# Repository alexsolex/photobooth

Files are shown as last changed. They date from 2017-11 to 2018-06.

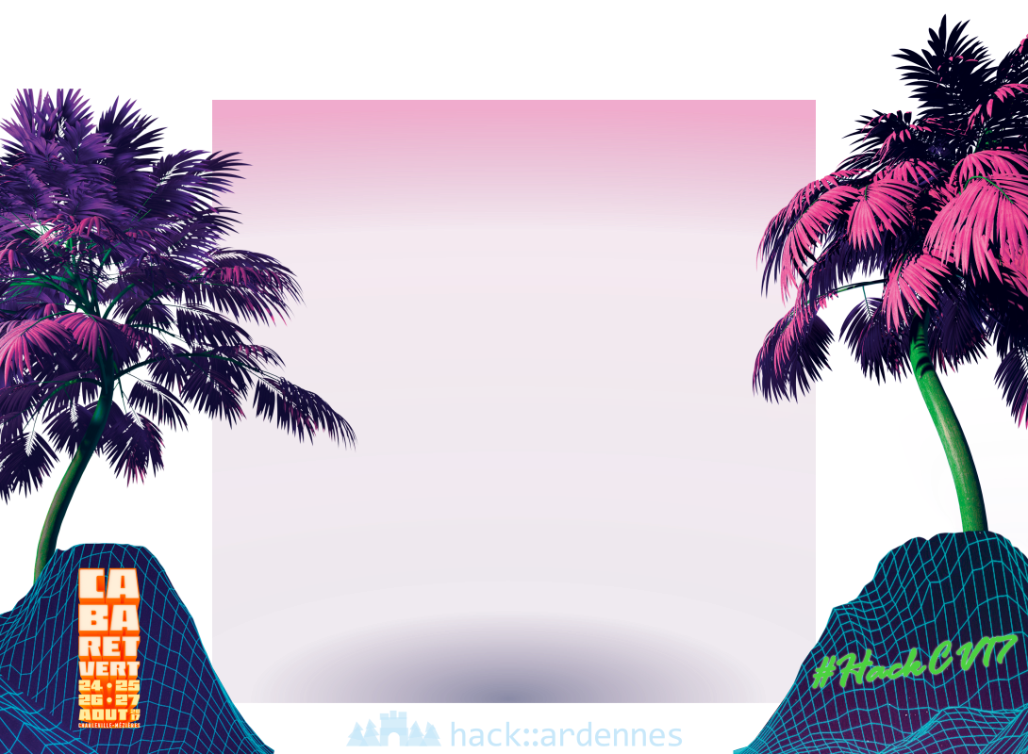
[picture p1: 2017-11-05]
stickers.png

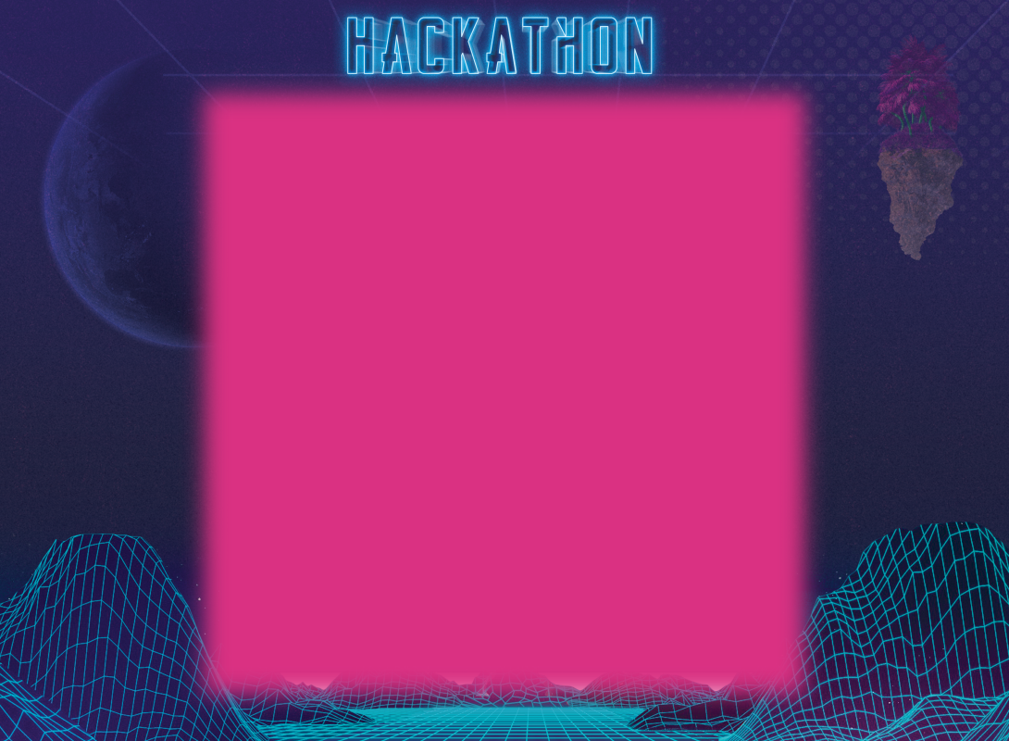
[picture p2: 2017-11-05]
background.png

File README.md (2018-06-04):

photobooth
==========

_**Photobooth made for raspberry pi**_

## matériel

Cette liste peut être adaptée selon les besoins, elle ne concerne que le matériel *électrique*/*électronique*

* 1 x Ecran avec alimentation (récupération)

* 1 x Cable écran avec adaptateur éventuel vers HDMI (dépend de la connectique de l'écran)

* 1 x Raspberry PI 3

https://www.amazon.fr/Raspberry-Pi-Carte-M%C3%A8re-Model/dp/B01CD5VC92

* 1 x Carte Micro SD classe 10

* 1 x Alimentation adaptée au Raspi (5V 3A)

https://www.amazon.fr/Aukru-Chargeur-Adaptateur-Alimentation-Raspberry/dp/B01566WOAG

* 1 x Pi Camera avec sa nappe

https://www.amazon.fr/Raspberry-Pi-1080p-Module-Cam%C3%A9ra/dp/B01ER2SKFS

* 1 x Relais 5V - 220V/10A

https://www.amazon.fr/dp/B019GTTS3K/

* 2 x lampes GU10 avec supports (par exemple mais peut être remplacé par l'éclairage de son choix, voir pourquoi pas une lampe extérieur, attention au courant consommé par les lampes qui doit être inférieur au courant que peut piloter le relais )

https://www.amazon.fr/Projecteur-Encastr%C3%A9-Douille-Ampoule-Halog%C3%A8ne/dp/B01JLNBVDQ

* 1 x connecteur c14 avec fusible et interrupteur

https://www.amazon.fr/alimentation-interrupteur-module-admission-broches/dp/B00F4MFMXE

* 1 x cable alimentation 220V PC C13

https://www.amazon.fr/Dexlan-Cordon-électrique-secteur-standard/dp/B0009M14YK

* 2 x boutons poussoirs type arcade

https://www.amazon.fr/Cewaal-Shaped-Convexity-Replacement-Illuminated/dp/B075SBK17G

* Des fils de cablage pour connecter sur le port GPIO du RPi

https://www.amazon.fr/s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

__Autre matériel__

* 1 x multiprise 220v (pour connecter l'écran et l'alimentation de raspberry)
* Du fil électrique 1.5mm² (cablage des lampes)
* Des dominos pour le raccordement électrique
* un fer à souder / de l'étain

## Installation (WIP)

__Prérequis :__
* J'ai choisi volontairement de ne pas rentrer dans les détails de l'utilisation d'un raspberry pi.  
* Raccorder son raspberry Pi au réseau et à internet pour effectuer les mises à jours et autres installations
* Brancher clavier/souris et écran ou se connecter en SSH pour effectuer les manipulations
* Avoir quelques notions d'électricité (ATTENTION quand vous manipulez du 220v !)
* Avoir quelques notions d'électronique

### Software (WIP)

1. Installer Raspbian sur la carte microSD et procéder à toutes les mises à jour  
 `sudo apt-get update `  
 `sudo apt-get dist-upgrade `  
 `sudo rpi-update `  ( Je déconseille celle-ci car elle a ruiné la résolution de mon écran, j'ai du réinstaller rasbian pour retrouver un setup fonctionnel)
 Puis reboot  
 
0. Configurations sur raspbian
La plupart de ces configurations se font soit depuis l'interface graphique soit via la console en tapant `sudo raspi-config`
* Connexion au réseau internet
* Configuration du hostname (utile lorsqu'on ne connait pas à priori l'adresse IP)
* Clavier en FR
* Locale en FR / France/ UTF8
* Timezone Europe/Paris (très important étant donné que les photos seront horodatées avec l'heure système)
* (Wifi country FR)
* Enable Camera + reboot
* Enable SSH + reboot
* Enable I2C + reboot
* Underscan = disabled (j'avais des bordures inutilisées sur l'écran)
* Changement du mot de passe de l'utilisateur `pi`  
`sudo passwd pi` puis saisie 2 fois du nouveau mot de passe  
`sudo reboot`
* extension du filesystem pour occuper la totalité de la carte mémoire  
`sudo raspi-config`  
(pensez à vérifier régulièrement que les configurations sont correctement prises en compte `sudo reboot`)
* installation du driver v4l2 (Attention il s'agit de la lettre L minuscule entre le 4 et le 2)  
`sudo nano /etc/modules`  
Ajouter la ligne suivante :  
`bcm2835-v4l2`  
* Préserver la carte SD en installant des logs dans la mémoire
`sudo nano /etc/fstab`  
ajouter  
`tmpfs /var/log tmpfs defaults,noatime,nosuid,mode=0755,size=100m 0 0`
On peut ajouter également les dossiers suivants :
`tmpfs /tmp tmpfs defaults,noatime,nosuid,size=100m 0 0`  
`tmpfs /var/tmp tmpfs defaults,noatime,nosuid,size=30m 0 0`  
``tmpfs /var/log tmpfs defaults,noatime,nosuid,mode=0755,size=100m 0 0`  
`tmpfs /var/run tmpfs defaults,noatime,nosuid,mode=0755,size=2m 0 0`  
`tmpfs /var/spool/mqueue tmpfs defaults,noatime,nosuid,mode=0700,gid=12,size=30m 0 0`  

3. Installer/mettre à jour les librairies python : (version indicatives basées sur mon setup d'origine)

  * pip pour installer les librairies (8.1.2) (déjà installé sur raspbian)
  * dropbox (4.0)  
  `sudo pip install dropbox`
  * facebook-sdk (2.0.0)  
  `sudo pip install facebook-sdk`
  * piexif (1.0.8) !! ATTENTION !! La version 1.0.10 ne fonctionne pas  
  `sudo pip install piexif==1.0.8`
  * qrcode (5.0.1)  
  `sudo pip install qrcode`
  * pygame (1.9.2a0) (déjà installé sur raspbian)
  * picamera (1.13) (déjà installé sur raspbian)
  * Pillow (2.6.1)  (déjà installé sur raspbian)  
  `sudo pip install pillow`
  * RPi.GPIO (0.6.3)  (déjà installé sur raspbian)  
  `sudo pip install rpi.gpio`
  * twython (3.3.0)  (déjà installé sur raspbian)  
  `sudo pip install twython` 
0. installer le script photobooth  
`sudo git clone https://github.com/alexsolex/photobooth.git`
0. enlever le fichier dummy.txt du répertoire shots (à corriger)  
`sudo rm dummy.txt`
0. Tester la caméra  
`raspistill -o image.jpg` doit afficher la vue de la caméra pendant quelques secondes puis fermer
0. Désactiver la led de la picamera(optionnel mais évite la chauffe)  
Editer le fichier config `sudo nano /boot/config.txt`  
Puis ajouter la ligne suivante à la fin : `disable_camera_led=1`

0. Désinstaller la suite libreoffice ainsi que d'autres applications inutiles.  
`sudo apt-get remove --purge libreoffice*`  
`sudo apt-get clean`  
`sudo apt-get autoremove`  

#### Configuration du photobooth

##### Envoyer les photos sur un compte dropbox

1. Aller sur https://www.dropbox.com/developers/

2. Créer une app :

* ChooseAPI : Dropbox API
* Choose the type of access you need : App folder
* Name your app : (doit être unique) mySuperPhotoboothDropbox
* [Create app]

3. Chercher `Generated access token`, puis cliquer sur `[Generate]` pour récupérer le token (chaine alphanumérique)

Configurer Dropbox pour votre photobooth :

Editer le fichier `setup.py`, trouver et modifier les lignes comme suit

> `DROPBOX_UPLOAD = True`  
> `dropboxToken = "coller_ici_le_token_généré_précédemment"`

0. Lancer le photobooth automatiquement au démarrage (TODO)

Editer le fichier /etc/rc.local et ajouter les commandes :  
>`cd /home/pi/photoboothfolder`  
>`sudo python photobooth.py`  

### Hardware (WIP)

#### Notes préliminaires
Je n'expliquerais pas ici la construction du boitier, chacun pouvant le réaliser selon ses compétences, ses besoins ... Cependant voici quelques remarques constaté avec l'usage :

* Pensez à la stabilité du photobooth. Il va être manipulé par plein de monde et certainement aussi des enfants !
* Pensez aux enfants : si les boutons sont trop haut, les enfants risquent de se mettre en danger (monter sur une chaise) ou encore de s'accrocher au photobooth pour pouvoir le manipuler
* Les utilisateurs regarderont l'écran pendant la prise de vue mais pas la caméra : La caméra devra être au plus proche de l'écran de manière à ce que le regard ne semble pas trop décalé sur la photo.
* Les lampes s'allumeront pendant la prise de vue (pour adapter l'autofocus) ce qui éblouira les utilisateurs. Pensez-y dans la conception et adaptez la position des lumières pour un compromis éclairage suffisant, mais pas trop éblouissant.

#### Câblage
ATTENTION : vous trouverez sur le net des schémas de numérotation du port GPIO correspondant à votre raspberry. 

Relais pour le flash (3 fils):  
\+ ---> pin #2 (5v PWR)  
\- ---> pin #14 (GND)  
s ---> pin #15 (GPIO22)

Bouton rouge (prise de vue / annulation) :  
Pin #6 (GND)  
Pin #7 (GPIO4)

Bouton bleu (enregistrement / diaporama) :  
Pin #8 (GPIO14)  
Pin #9 (GND)

Les boutons ont été câblés avec une résistance de tirage en série et un condensateur (valeur à préciser) pour éviter les parasites et les rebonds de contact (debounce)

## Boitier
Ce paragraphe est indicatif afin de vous donner des pistes sur sa réalisation.

J'ai pour ma part réalisé le mien en DAO (autocad en licence etudiant/professeur). J'ai mesuré au pied à coulisse tous les encombrements des éléments à positionner (écran, boutons, lampes, prises usb et ethernet, prise femelle 200v et interrupteur), que j'ai redessiné sur autocad afin de prévoir les encombrement dans le boitier.

Les plans ont été réalisés afin d'être utilisés par une découpe laser. 

J'ai pris soin de connaitre l'encombrement maximum supporté par la découpe laser afin de pouvoir faire les découpe en un seul morceau. J'ai également demandé au fablab l'épaisseur (kerf) du laser (0.1mm dans mon cas). Ceci est utile car j'ai fait un assemblage de type "cross fingers" et il faut prendre en compte l'épaisseur de la découpe afin que les morceaux s'assemblent en forcant pour assurer le maintien.

Pour dessiner les "cross fingers" j'ai utilisé un outil en ligne : https://makeabox.io ce qui est tout de même bien plus simple que le faire à la main :). Cet outil génère un fichier pdf qu'on peut réimporter dans autocad pour le modifier et y dessiner les autres parties à découper.

Remarque : J'ai utilisé du médium 6mm qui était la limite que pouvait découper le laser en épaisseur (j'ai donc eut de la chance mais le fablab a du réutiliser un medium certainement de meilleure qualité). A de telles épaisseurs de découpe, le faisceau laser qui est conique a tendance à bruler plus la partie supérieur que la partie inférieure, ce qui engendre des découpes en biseau assez visibles. Cependant cela n'a pas empêché le montage final.

Les plans que j'ai utilisé sont disponibles dans le dossier 'documentation' du dépôt.

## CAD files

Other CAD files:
documentation/photobooth_plan_decoupe.dwg

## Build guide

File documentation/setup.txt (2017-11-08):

A faire pour préparer le RPI (documentation à réaliser)
- installation de rasbian + màj
- activation SSH
- faire de la place sur rasbian 
	(nettoyer le superflux)
- install / MàJ Python
- dépendances python 
	- pygame
	- PIL
	- ...
- setup picam
- Cablage GPIO
- Mise à jour de l'horloge auto sur internet

(et sans doute d'autres choses qui m'échappent)

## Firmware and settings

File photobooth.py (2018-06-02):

# -*- coding: utf-8 -*-

import pygame
import pygame.camera
from pygame.locals import *
import time,random,datetime
import shutil,os.path
from PIL import Image, ImageOps, ImageEnhance, ImageDraw, ImageFont
import socket
import fcntl
import struct
import config
import facebook
import piexif
#TODO
# - ajouter une option pour permettre de ne pas activer le slideshow
# - ajouter un timeout pour lancer le slideshow sur l'accueil 
# - Faire un système de lancement automatique de la prise de vue (pour attirer l'attention avec les flash)
# - terminer la factorisation des paramètres
# - améliorer la configuration (wifi, ...)
#DONE
# - design global
# - compte à rebour sur les différentes étapes
# - grossir le logo
# - appui sur A lors du compte à rebour pour revenir à la préparation
# - prévoir l'absence de réseau
# - ajouter le logo hackardenes sur le polaroid
# - réduire le polaroid pour ne pas perdre en qualité sur la photo
# - réparer le décompte avant abandon de la photo

############################################################################################
#  CONFIGURATION                                                                           #
############################################################################################

# Pour envoyer les tweets sans les messages 'officiels' (True : le message est basique / False : le message est aléatoire parmis les messages configurés)
TEST = False 

# Mode Debug : DEBUG = True pour ne pas envoyer de tweet du tout / False pour envoyer des Tweets
DEBUG = False

# Transform the picture into a polaroid photographe
RENDER_AS_POLAROID = True

# use a white background to act like a flash when shooting picture
USE_SCREEN_AS_FLASH = False

# Run the booth in full screen
RUN_FULLSCREEN = True

# if not full screen, size of the window
WINDOWED_MODE_SIZE = (800,800)

# use GPIO for button and/or flash
USE_GPIO = True

# Camera settings 
HFLIP = False
VFLIP = True

# FIN DE LA CONFIGURATION
#######################################################

# QRcode temporaire
QRCODE_FILENAME = "_temporaryQRCode.jpg"
# Nom des fichiers temporaires
TEMPORARY_FILENAME = "_temporary.jpg"
# polaroid filename
POLA_FILENAME = "_pola"+TEMPORARY_FILENAME #+".png"
# TODO : modifier le chemin et distinguer la photo prise de la photo générée
#TEMP_SHOOT_FILENAME = "shoot.jpg" #photo prise brut
#TEMP_PICTURE_FILENAME = "temporary.jpg" #photo travaillée

    
# imports facultatifs selon les options
if config.DROPBOX_UPLOAD:
    import dropbox
    dbx = dropbox.Dropbox(config.dropboxToken)
    if config.SHOW_DROPBOX_QRCODE:
        import qrcode

if config.SEND_ON_TWITTER:
    # clean the bad messages
    for m in config.Tweets_msgs:
        if len(m) > 117:
            print u"Suppression du message \"{0}\" car il dépasse la taille maxi".format(m)
            config.Tweets_msgs.remove(m)
    #check if list contain any message
    if len(config.Tweets_msgs)==0:
        raise Exception("ERROR : message for twitter are not correct")
    # import twitter python library
    from twython import Twython

FLASH_ON = True #False : interrupteur normalement fermé / True : interrupteur normalement ouvert
FLASH_OFF = not FLASH_ON
    
if USE_GPIO: #TODO : ajouter de l'électronique pour les boutons et un flash
    import RPi.GPIO as GPIO
    GPIO.setmode(GPIO.BOARD) # use board pin numbers
    # define pin #7 as input pin
    pin_buttonA = 7
    pin_buttonB = 8
    led1_pin    = 15 # LED 1
    GPIO.setup(led1_pin,GPIO.OUT) # LED 1
    GPIO.output(led1_pin, FLASH_OFF) #prepare off
    GPIO.setup(pin_buttonA, GPIO.IN, pull_up_down=GPIO.PUD_UP) 
    GPIO.setup(pin_buttonB, GPIO.IN, pull_up_down=GPIO.PUD_UP) 

# initialisations
pygame.init()
pygame.camera.init()
clock = pygame.time.Clock()

# Variables
frame_rate = 50

# pré-chargement des images en cache pour pygame
image_cache = {}
def get_image(key):
    """Pre-chargement des images pour améliorer les perf"""
    if not key in image_cache:
        image = pygame.image.load(key)
        if image.get_alpha() is None:
            image = image.convert()
        else:
            image = image.convert_alpha()
        image_cache[key] = image
    return image_cache[key]

def make_polaroid(infile, outfile):
    import PhotoMontage
    montage = PhotoMontage.make_montage(infile)

    #create exif datas
    zeroth_ifd = {piexif.ImageIFD.Make: u"PiCamera HackArdennes",
                  piexif.ImageIFD.Software: u"Photobooth HackArdennes"
                  }
    exif_ifd = {piexif.ExifIFD.DateTimeOriginal: datetime.datetime.today().strftime('%Y:%m:%d %H:%M:%S'),
                piexif.ExifIFD.UserComment: config.PICTURE_EXIF_COMMENT}
    exif_dict = {"0th":zeroth_ifd, "Exif":exif_ifd}
    exif_bytes = piexif.dump(exif_dict)
    
    #Save as good quality ;) with exif metadatas
    montage.save(outfile, 'JPEG', subsampling=0, quality=100, exif=exif_bytes)   

def getATweet():
    """return a random choice for tweets"""
    return random.choice(config.Tweets_msgs)

def Tweet(message, picturefile):
    """Send the message as a Status with the picture"""
    print u"tweeting <<{0}>> with file '{1}'...".format(message,picturefile)
    if not DEBUG:
        twitter = Twython(config.apiKey,config.apiSecret,config.accessToken,config.accessTokenSecret)
        image_open = open(picturefile)
        image_ids = twitter.upload_media(media=image_open)
        tweetmsg = message
        if TEST:
            tweetmsg = "Photo envoyée le {0} #photobooth".format(time.strftime("%d/%m/%Y à %H:%M:%S"))

    try:	
        twitter.update_status(status = tweetmsg,media_ids = image_ids['media_id'])
    except Exception as e:
        print e.message

    print "done !"
 
def send_pic_FB(filename,message="Envoi automatique depuis le photobooth HackArdennes"):
    """send the picture 'filename' on the facebook album with the 'message' text""" 
    graph = facebook.GraphAPI(config.FB_ACCESS_TOKEN)
    print("Adding %s to the album ID#%s."%(filename,config.FB_ALBUM_ID))
    graph.put_photo(image       = open(filename, 'rb'),
                    album_path  = config.FB_ALBUM_ID + "/photos",
                    message     = message
                    )
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

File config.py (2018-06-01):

# -*- coding: utf-8 -*-
#Cabaret vert
# Do you want to save all the approved picture with a distinct name on your Pi ?
#   True : Save the approved pics 
#   False : pics are not saved locally
SAVE_IN_FOLDER = True
# Specify the local relative folder where the pics will be saved
PHOTOS_PATH = "shots"

# Keep the original picture with no photomontage
KEEP_ORIGINAL_PIC = False

DISPLAY_IP_ADDRESS = False

# To display pictures slideshow, use secondary button.
# Set to True, to use the slideshow, False will prevent the use of slideshow
USE_SLIDESHOW = True

# We use Exif meta datas to store informations about the picture. Please set a comment to set in the exifs metas here
PICTURE_EXIF_COMMENT = u"Photo prise par le Photobooth HackArdennes !"

#
# FACEBOOK
#
SEND_ON_FACEBOOK = False

#Obtenir les tokens :
#   1/ aller sur l'explorateur de l'API graph ( https://developers.facebook.com/tools/explorer/ ) et choisir l'app Photobooth HackArdennes
#   2/ cliquer sur 'get Token' puis sur 'get user access token' pour obtenir un token utilisateur de courte durée : cocher 'publish actions', 'manage pages', et 'publish pages' puis 'Get access token'
#       --> ...
#   3/ nouvel onglet suivre le lien ci dessous (en remplacant les chants entre {}) pour échanger le token de courte durée contre un de longue durée 
#       https://graph.facebook.com/oauth/access_token?client_id={APP_ID}&client_secret={APP_SECRET}&grant_type=fb_exchange_token&fb_exchange_token={EXISTING_ACCESS_TOKEN}
#           APP_ID = "..."
#           APP_SECRET = "..."
#           EXISTING_ACCESS_TOKEN = short token
#       --> ...
#   4/ revenir sur l'explorateur de l'APIgraph et coller le token de longue durée obtenu, puis 'get token' puis choisir la page désirée (hackardennes)
#       --> ...
#   5/ copier le nouveau token dans le champ "Jeton d'accès" : c'est votre jeton qui devrait être définitif


FB_ACCESS_TOKEN = "..."
FB_ALBUM_ID = "..." 

FB_PICTURE_TEXT = "Commentaire accompagnant la photo sur un partage facebook"

#
# WORDING
#
TXT_WAIT_SCREEN  = u"\u00AB #HackCV17 \u00BB\n"
TXT_WAIT_SCREEN += u"\n"
TXT_WAIT_SCREEN += u"Laissez un souvenir de votre passage !\n"
TXT_WAIT_SCREEN += u"\n"
TXT_WAIT_SCREEN += u"Prenez vous en photo et\n"
TXT_WAIT_SCREEN += u"retrouvez la sur notre page\n"
TXT_WAIT_SCREEN += u"www.facebook.fr/hackardennes\n"
TXT_WAIT_SCREEN += u"\n"
TXT_WAIT_SCREEN += u"Appuyez sur le bouton rouge pour commencer !"
#TXT_WAIT_SCREEN += u"\n"

TXT_APPROVE_PIC = u"Bouton bleu pour conserver cette photo..."
TXT_CANCEL_SEND = u"Cette photo n'a pas été enregistrée\n\nBouton rouge pour recommencer."
TXT_SENDING_FB  = u"Mise en orbite de votre photo en cours..."
TXT_PIC_SENT    = u"Photo enregistrée, partagez-la :\nwww.facebook.fr/hackardennes !\nMerci !"


#
# OUTPUT PICTURE
#

#
# COLORS
#
GLOBAL_FONT_COLOR = (255,91,255)
BACKGROUND_COLOR = (11,42,81)
COUNTDOWN_FONT_COLOR = (255,34,43)

#
# FONTS (filenames must be stored at script root)
#
FONT_FILE = "FrontageCondensed-Regular.ttf"
COUNTDOWN_FONT_FILE = "Consolas.ttf"

#
# LOGO OF ORGANISATION
#
OWNER_LOGO = "logo_4_b.png"

#
# TWITTER
#

# Do you want to send the approved picture on twitter ?
#   True : Send the pic on twitter
#   False : bypass the twitter thing
# (set your twitter credentials with the account you wish to send the picture)
SEND_ON_TWITTER = False

# Twitter credentials
apiKey = ""
apiSecret = ""
accessToken = ""
accessTokenSecret = ""

# List all the messages you want to randomly use to post the approved pictures over twitter
#   /!\ Messages have to be shorter than 127 char (140 max twitter message size - 23 char for the picture url)
#       Messages longer than 127 char will be discarded from the random messages
Tweets_msgs = [
    # you can use the bottom numbers to know the size of your message
    # 0        1         2         3         4         5         6         7         8         9        10        11"
    # 123456789012345678901234567890123456789012345678901234567890123456789012345678901234567890123456789012345678901234567"
    u"Ceci est un tweet photo. Attention au blocage du compte !!",
    #|<------------------------------------------------------------ messages MUST be shorter than this limit ------------>|
    ]

#
# DROPBOX
#

# Do you want to upload the approved picture on a dropbox app folder ?
#   True : Send the picture on the dropbox app folder
#   False : bypass the Dropbox upload
DROPBOX_UPLOAD = False
# Do you want to display a QRcode pointing to the dropbox uploaded picture file ?
#   True : show the QRcode
#   False : bypass the QRcode generation
SHOW_DROPBOX_QRCODE = False

# Aller sur https://www.dropbox.com/developers/
#   Créer une app :
#       ChooseAPI : Dropbox API
#       Choose the type of access you need : App folder
#       Name your app : (doit être unique) mySuperPhotoboothDropbox
#       [Create app]
#   Chercher Generated access token, puis cliquer sur [Generate]
#       pour récupérer le token (chaine alphanumérique)
dropboxToken = "...."

# Compte à rebourg avant la prise de vue
TIME_BEFORE_SHOOT = 5 # x secs running before shooting
# Délai avant l'abandon de l'attente d'approbation de l'utilisateur
TIMEOUT_APPROVAL =  15 # Après ce délai, sans action de l'utilisateur, l'envoi de la photo est annulée
# Délai d'attente après l'envoi de la photo
TIMEOUT_AFTER_SENT = 30 # x secs to tell the pic has been sent
# Délai global avant retour à la page d'attente
TIMEOUT_NO_ACTION = 14 # x secs without action to go back to wait status
# Durée d'affichage entre 2 photos en mode diaporama
TIMEOUT_NEXT_SLIDE = 2 # x secs

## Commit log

2018-02-13 Liste de matériel
2018-02-14 ajout de la carte micro SD dans la liste du matériel
2018-05-14 enrichissement de la doc
2018-05-26 ajout d'informations pour la configuration
2018-05-30 documentation (moins de WIP et plus complet)
2018-06-01 print correctly message exception
    [photobooth.py]
2018-06-02 dummy file in the shots dir causes error in slideshow
    [photobooth.py]
2018-06-04 added autocad dwg part file for lasercut
    [photobooth_plan_decoupe.dwg]
2018-06-04 added infos about the case conception
